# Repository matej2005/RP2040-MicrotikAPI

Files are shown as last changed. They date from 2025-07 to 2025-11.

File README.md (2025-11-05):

# RP2040-MicrotikAPI
This project is used to enable / disable firewall rule using RouterOS rest API

Project is based on RP2040-zero dev board and W5500 ethernet module

Powering via USB-C

✅	- tested
☑️ - it should work
❔ - not tested
❌ - not compatible
⌚ - in progress

| Board | Compatibility status |
|--|--|
| RP2040-zero + W5500 | ✅ |
| RP2350-zero + W5500 | ❌ ⌚ |
| W5500-EVB-Pico |❔ ☑️  |
| W5500-EVB-Pico-PoE | ✅ | 
| W55RP20-EVB-PICO | ❌ |
| W6300-EVB-Pico | ❌ |
| W6100-EVB-Pico | ❌ |
| W5100S-EVB-Pico | ❌ |
| W6300-EVB-Pico2| ❌ |
| W6100-EVB-Pico2| ❌ | 
| W5500-EVB-Pico2 |❔ ☑️ |
|W5100S-EVB-Pico2| ❌ |

## Building it
Here is schematic how to connect ethernet module with RP2040-zero
Sometimes it started happening that ethernet module can´t boot, it was happening most times with long USB cable. I fixed it by adding cappacitor to the 3.3V power line.
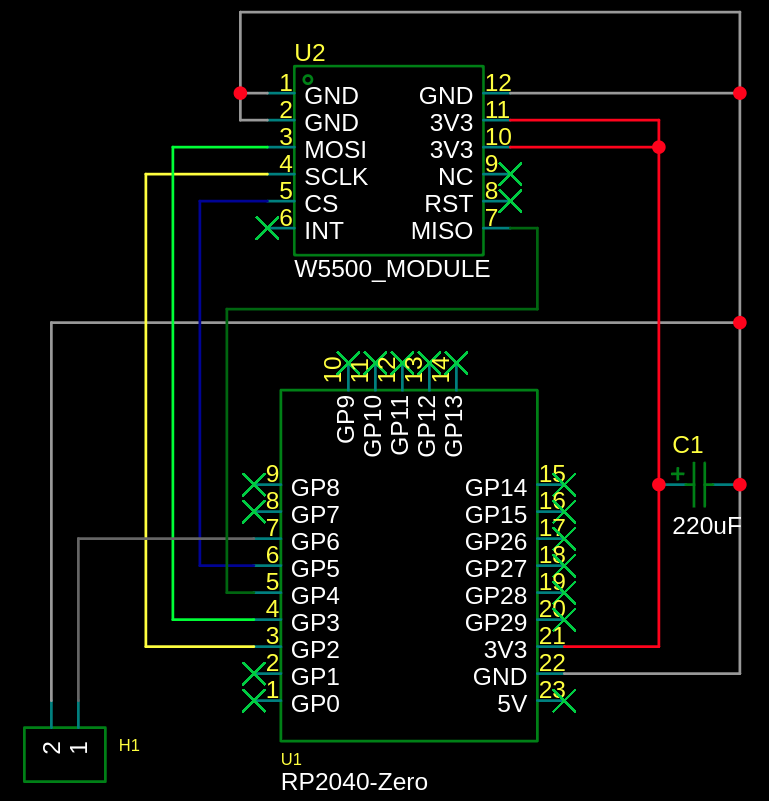
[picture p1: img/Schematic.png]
Schematic


I builded it on pice of protoboard
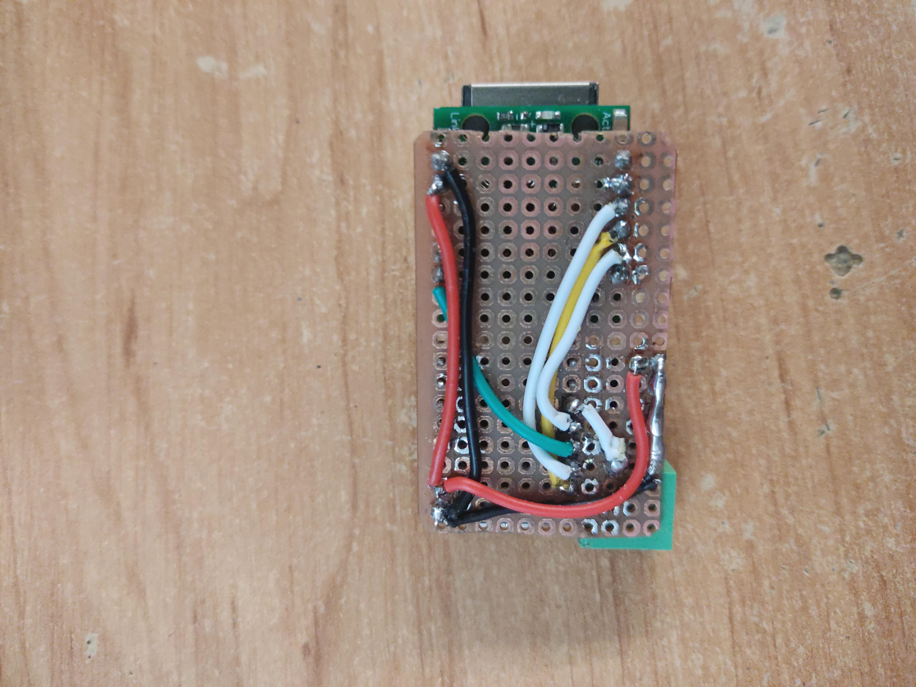
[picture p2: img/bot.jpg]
protoboard top

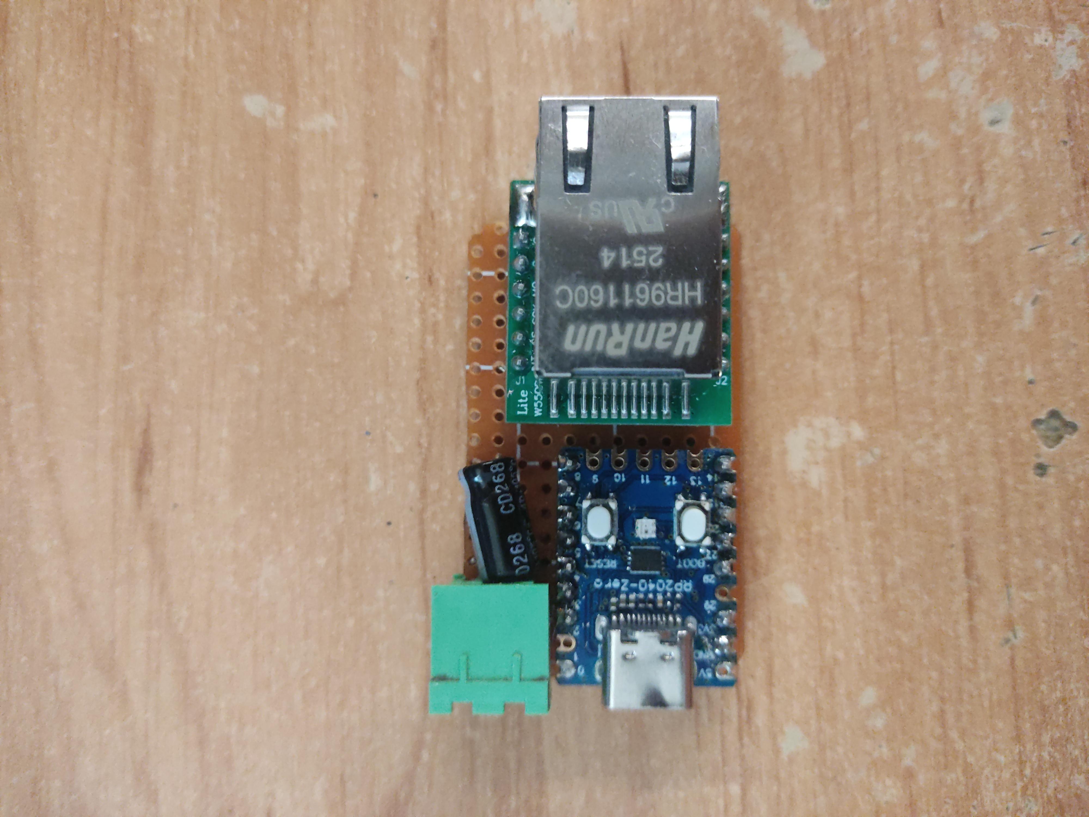
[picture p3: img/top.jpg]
protoboard bottom


## Enclousure
I 3D printed rackmount case for this project
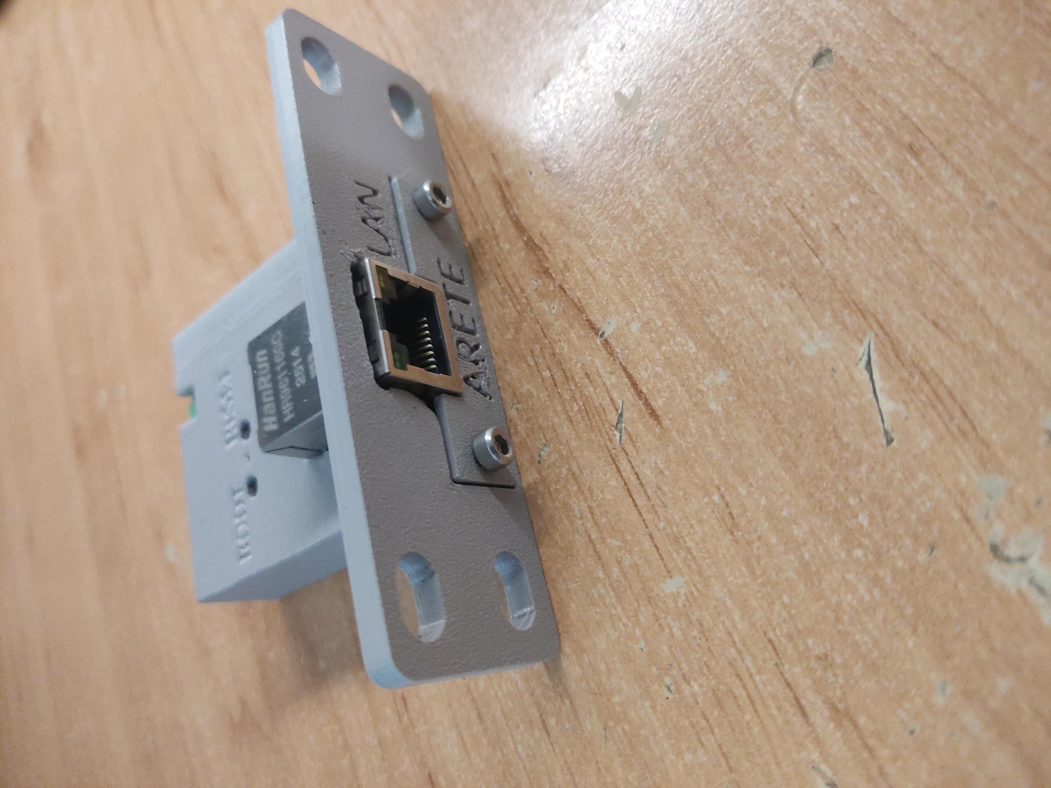
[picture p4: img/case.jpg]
Enclousure


## W5500-EVB-Pico
Code is compatible with W5500-EVB-Pico board. This board combine raspberry pi pico and W5500 ethernet module.
Led indication not working.
[W5500-EVB-PICO documentation](https://docs.wiznet.io/Product/iEthernet/W5500/w5500-evb-pico)

## RouterBoard configuration
**Supported versions > RouterOS v7.1beta4**
 - Login in to your router using WinBox
 - Optional: Create Group API in `system/groups` with policy `write, rest-api, read, api`
 - In `system/users` create user for accessing via API with api group created before
 - Optional reserve DHCP address for this device and add it under Allowed addresses
 - Make sure that in `IP/Services` WWW is enabled
 - Create firewall rule with some specific comment that we will be targeting ex:"GPIO controled port" 
	
Terminal
 - `user/group/add name=routerOs-deck policy=read, write, api, rest-api comment="Group for roterOs-deck"`
 - `user/add name=api password=1234 group=routerOs-deck comment="User for rest-api"`
 - `ip/service/enable www`
 - `ip/firewall/nat/add comment="GPIO controled port"` ...

## Firmware

 - open MicrotikAPI/MicrotikAPI.ino in arduino ide
 - install Raspberry Pi Pico by earlephilhower using board manager
 - set target board as Waveshare RP2040 Zero or WIZnet W5500-EVB-Pico based on your board
 - install libraries
 - in file config.h
	- set `server[]` to RouterBoard IP
	- set `AUTH_USER` to user created in step 2.3
	- set `AUTH_PASSWD` to user password in step 2.3
	- set `targetVariableValue` to comment of targeted rule
 - Power On the device or push RESET while holding BOOT button
 - Compile and upload

[microtik rest-api doc](https://help.mikrotik.com/docs/spaces/ROS/pages/47579162/REST+API)

## V2 ideas
- use W5500-EVB-PICO
- web interface
- more gpio
- OTA
- stackable
- more apis

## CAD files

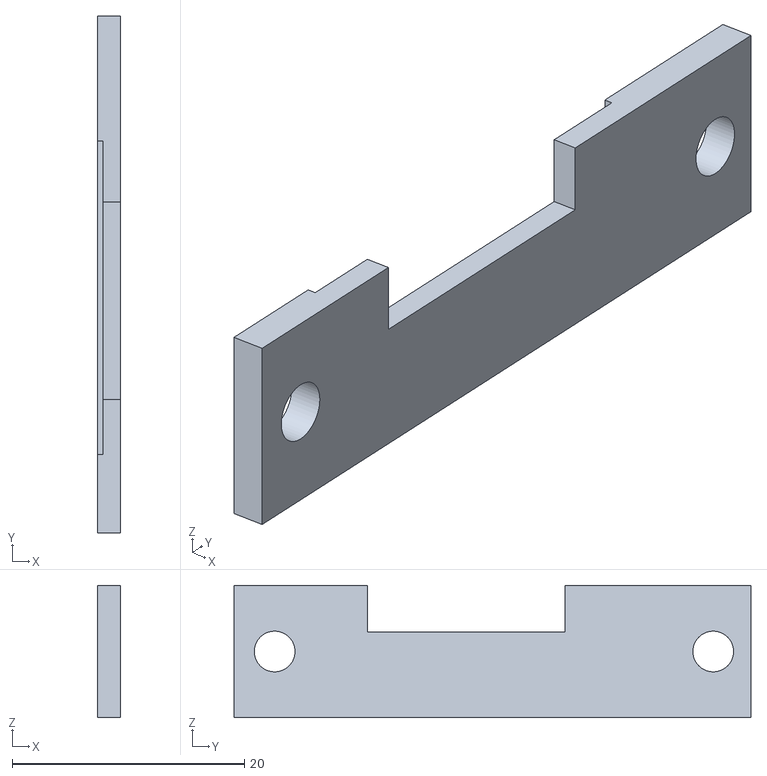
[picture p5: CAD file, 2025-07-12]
3D/Microtik-api-cover.stl
2.00 x 44.5 x 11.4

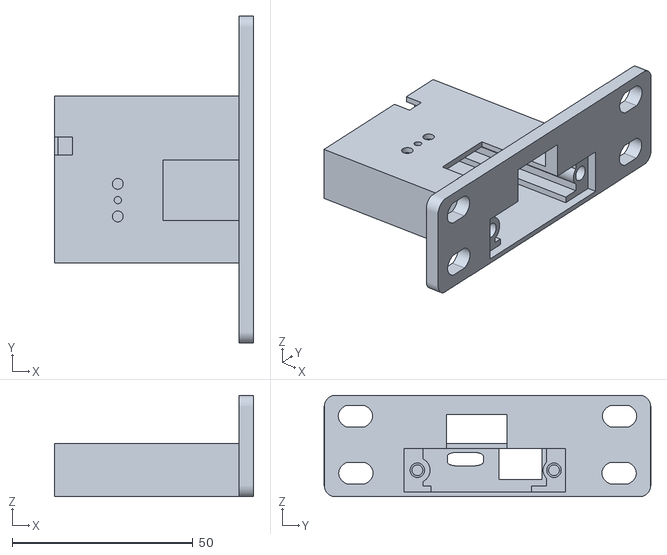
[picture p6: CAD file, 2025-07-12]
3D/Microtik-api-body.stl
55.0 x 90.2 x 28.0

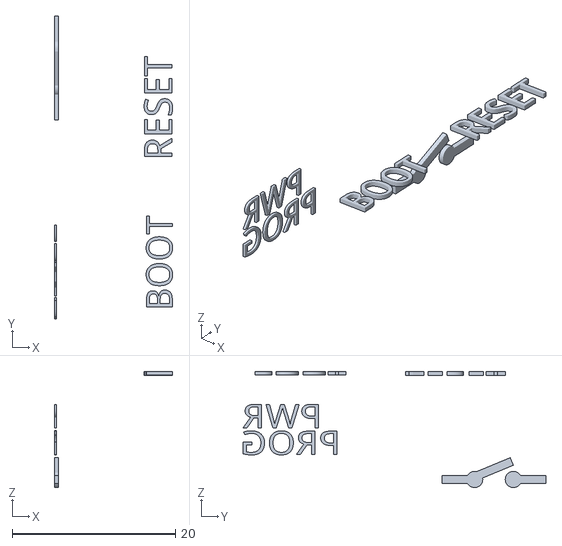
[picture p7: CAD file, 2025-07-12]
3D/Microtik-api-text.stl
14.5 x 37.2 x 14.2

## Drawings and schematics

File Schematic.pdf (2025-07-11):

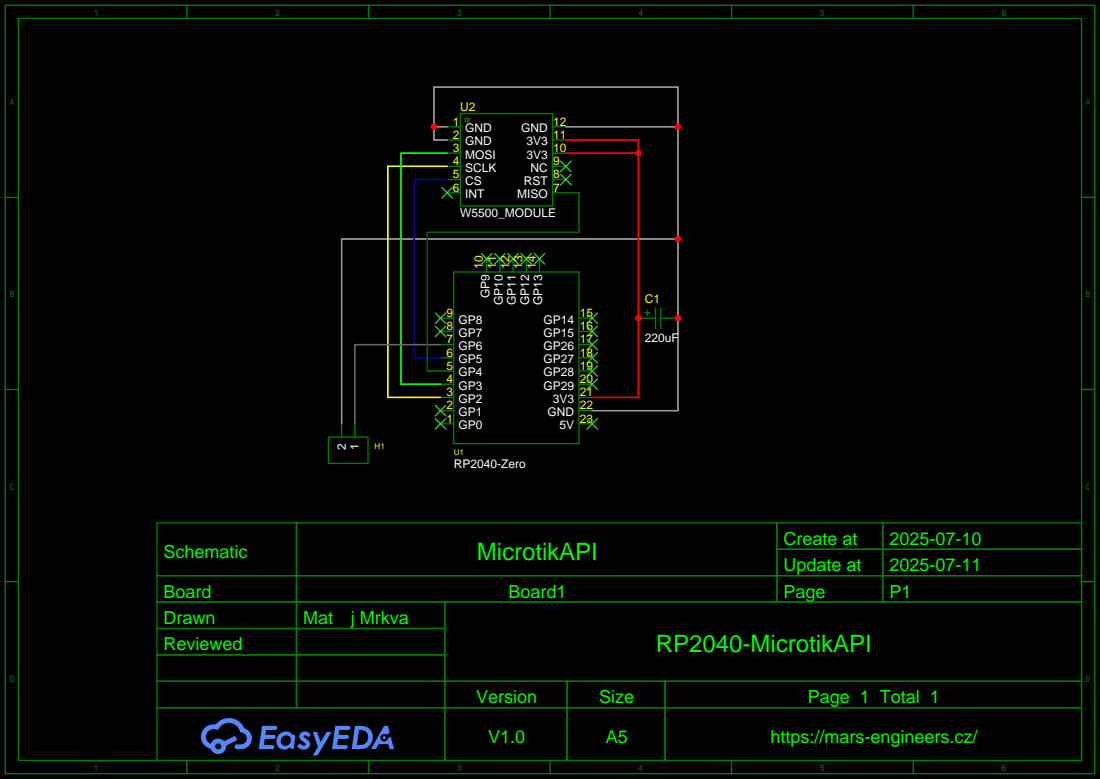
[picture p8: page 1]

Schematic | MicrotikAPI | Create at | 2025-07-10

Update at | 2025-07-11

Board | Board1 | Page | P1
Drawn | Mat j Mrkva | RP2040-MicrotikAPI
Reviewed

Version | Size | Page 1 Total 1
V1.0 | A5 | https://mars-engineers.cz/

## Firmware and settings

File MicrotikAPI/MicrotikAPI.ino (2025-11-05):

/*
 MicrotikApi https://github.com/matej2005/RP2040-MicrotikAPI

 This sketch connects to a routerboard
 using an WIZnet Ethernet board.

 Circuit:
 * Ethernet board attached to pins 2, 3, 4, 5

 created 18 Dec 2009
 by David A. Mellis
 modified 19 Jun 2025
 by Matěj Mrkva, based on work by Tom Igoe


 Libraries needed:
    Adafruit NeoPixel by Adafruit
    Ethernet
    ArduinoHttpClient by Arduino
    Arduino_JSON by Arduino
    Base64 by Xander
 */

#include <SPI.h>
#include <Ethernet.h>
#include "config.h"
#include <VFS.h>
#include <LittleFS.h>
#include <Arduino_JSON.h>


#if !(ARDUINO_ARCH_RP2040 | ARDUINO_WAVESHARE_RP2040_ZERO | ARDUINO_WIZNET_5500_EVB_PICO | ARDUINO_WIZNET_5500_EVB_PICO2)
#warning "Code is intended to run on RP2040/RP2350 architecture or Waveshare RP2040 Zero or W5500-EVB-Pico* board"
#endif

#define VERSION "1.1.0"


#if (ARDUINO_ARCH_RP2040)
#define CPU "RP2040"
#else
#if (PICO_RP2350A)
#define CPU "RP2350"
#else
#define CPU "na"
#endif
#endif



// Initialize the Ethernet client library
// with the IP address and port of the server
// that you want to connect to (port 80 is default for HTTP):
EthernetClient client;

bool inputState = false, lastInputState = false;
unsigned long currentMillis, lastMillis;

bool ethStatus, lastEthStatus, DHCP;

#ifdef PIN_NEOPIXEL
#include <Adafruit_NeoPixel.h>
Adafruit_NeoPixel pixels(LEDS, LED_GPIO, NEO_GRB + NEO_KHZ800);
#endif

enum Status {
  OK,
  INFO,
  WARN,
  ERROR,
  CLEAR
};

enum RequestTypes {
  GET,
  PATCH
};



void setup() {
  pinMode(INPUT_PIN, INPUT_PULLUP);
  // Ethernet.init(ETHERNET_CS_PIN);
  setupStatus();
  // Open serial communications
  Serial.begin(115200);

  delay(5000);

  Serial.print(F("Starting RouterOs-deck " VERSION " from " __DATE__ " by Matěj Mrkva\nProject: https://github.com/matej2005/RP2040-MicrotikAPI\nURL: https://mars-engineers.cz/ \nemail: matej.mrkva@mars-engineers.cz\n====================================================================================================\n"));

  prepareAuth();
  setupEthernet();

  LittleFS.begin();
  VFS.root(LittleFS);

  setupHtml();
  // give the Ethernet shield a second to initialize:
  delay(1000);
}

void loop() {
  loopHtml();

  currentMillis = millis();
  if (currentMillis - lastMillis >= 1000) {
    lastMillis = currentMillis;

    updateEthStatus();

    if (ethStatus != lastEthStatus) {
      lastEthStatus = ethStatus;
      if (ethStatus) {
        Serial.println("INFO: Ethernet cable is connected.");
        ethernetTryConnect();
      } else {
        setStatus(WARN);
        Serial.println("INFO: Ethernet cable is not connected.");
      }
    }
    if (ethStatus) {
      inputState = digitalRead(INPUT_PIN);
      if (inputState != lastInputState) {
        lastInputState = inputState;
        sendToApiState(inputState);
      }
    }
  }
}

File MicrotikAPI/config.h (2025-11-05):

#include <sys/_stdint.h>
//////////////////////////////
/*      Configuration       */
//////////////////////////////

#define USE_WEB
#define WEB_HTTP_PORT 80

// Pinout
#define INPUT_PIN 6
#define LEDS 1

#if ARDUINO_WIZNET_5500_EVB_PICO | ARDUINO_WIZNET_5500_EVB_PICO2
#define ETHERNET_CS_PIN 17u
#define LED_GPIO PIN_LED
#endif

#ifdef ARDUINO_WAVESHARE_RP2040_ZERO
#define ETHERNET_CS_PIN 5
#define LED_GPIO PIN_NEOPIXEL

#endif


// RouterOS configuration
char serverIp[] = "192.168.88.1";    // IP of the routerboard
const uint16_t port = 80;        // Port of http interface
const String AUTH_USER = "api";
const String AUTH_PASSWD = "1234";
const String targetVariable = "comment";                   // Targeted rule by variable
const String targetVariableValue = "GPIO controled port";  // Targeted rule by variable with value

const String URL_PATH = "/rest/ip/firewall/nat";  // REST url

// Network
byte mac[] = { 0xDE, 0xAD, 0xBE, 0xEF, 0xFE, 0xED };  // Mac of this device
//byte mac[] = {0x00, 0x08, 0xDC, 0x12, 0x34, 0x56};  // Mac of this device

// Set the static IP address to use if the DHCP fails to assign
IPAddress ip(192, 168, 0, 177);
IPAddress myDns(192, 168, 0, 1);


//#define DEBUG // Unccoment do enable debug

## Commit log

2025-07-10 Added arduino files
2025-07-10 Create schematic
2025-07-10 moved schematic to PDF
2025-07-11 Upload schematic
2025-07-11 Rename schematic
2025-07-12 Upload stl files
    [Microtik-api-body.stl, Microtik-api-cover.stl, Microtik-api-text.stl]
2025-07-13 W5500-EVB-Pico compatibility
2025-07-13 compatibylity with pico2 - not tested,fixed version
    [MicrotikAPI.ino, config.h]
